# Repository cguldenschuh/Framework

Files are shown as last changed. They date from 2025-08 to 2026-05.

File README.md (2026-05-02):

# Framework Destop Tile Generator

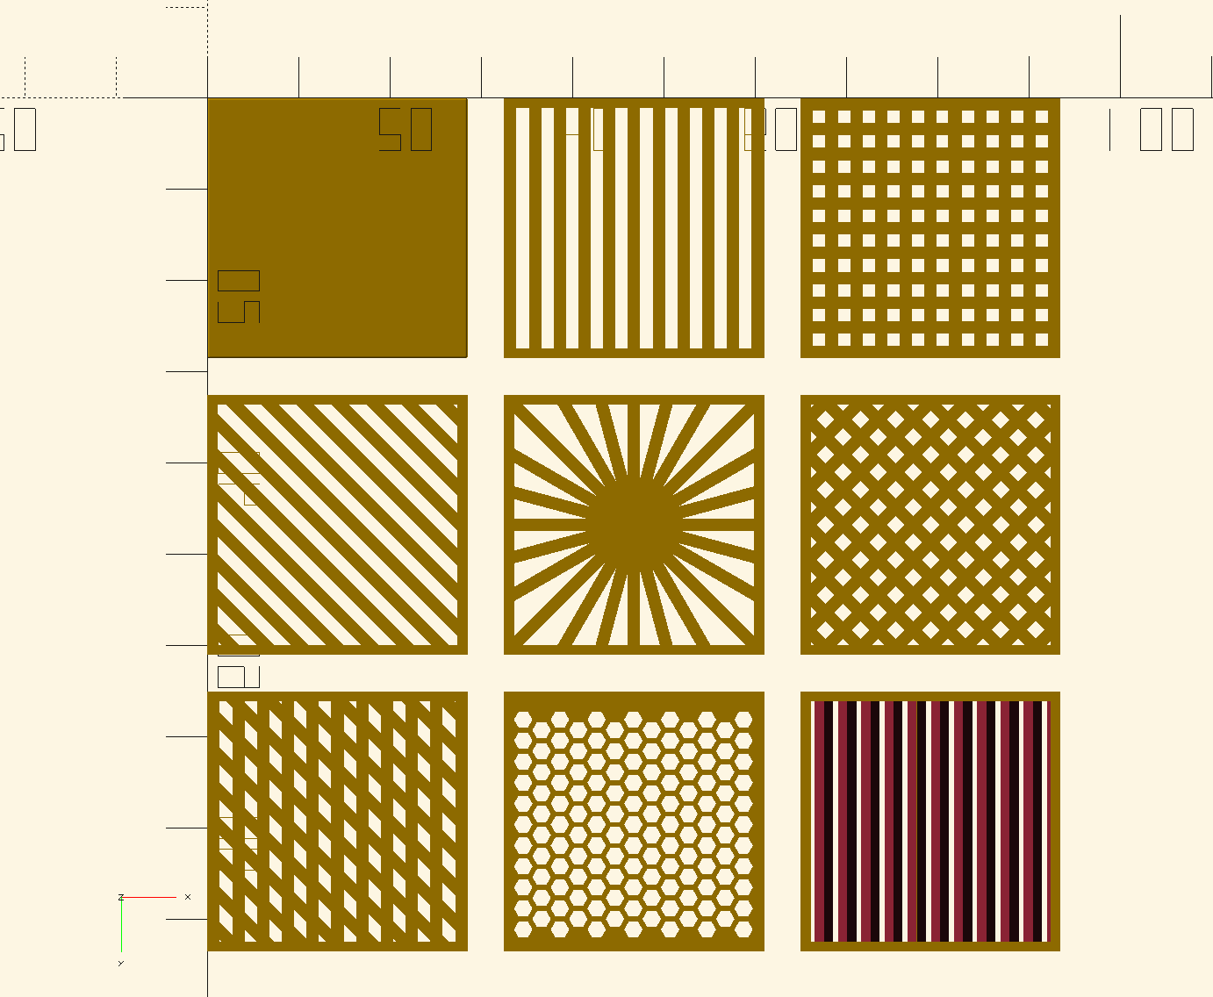
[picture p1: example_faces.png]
Example-Tiles


## License

Copyright © 2025 Charles Guldenschuh.  Licensed under CC BY 4.0.
To view a copy of this license, visit:

        https://creativecommons.org/licenses/by/4.0/

Included material:

- FRAMEWORK_DESKTOP_BLANK_TILE.stl from:
  
      https://github.com/FrameworkComputer/Framework-Desktop.git
  
  © 2025 by Framework Computer Inc is licensed under CC BY 4.0.er Inc is licensed under CC BY 4.0.

- lib_cutouts.scad (used by honeycomb) from:
  
      https://github.com/paul1522/OpenScad-Projects.git
  
  © 2019, MIT License

## What is it?

This is an OpenSCAD script to generate a handful of different tiles
for the Framework Desktop front panel.  Additionally, it can generate
multi-tile honeycomb or blank panels.

## Why is it?

* I had color preferences that weren't available from Framework
* I wanted some logo tiles that weren't available
* I'm a cheap SOB with time on my hands

## Caveats

1. These tiles fit relatively well. They are not quite as tightly bound
   to the faceplate as OEM tiles, but they won't fall out. My tiles have all
   been PLA printed on a Bambu P1S and seem to be dimensonally accurate.
2. Framework Computer has not reviewed and is not responsible for the use
   of tiles generated by this script.
3. The author assumes no responsibility for the use of this script.  To
   the best of my knowledge and testing, these tiles are akin to Legos in
   possible damage...
4. If you read the code, don't judge me... I'm retired and sometimes impatient
   with OpenSCAD, and so have generously sprinkled "magic" constants through out
   the script.  It'll get cleaned up, eventually, maybe.

## Usage

Easiest:

1. Place all of the files in one directory.
2. Open Framework_tiles_1.scad with OpenSCAD.
3. Open the **"Build Selection"** customizer section; All selections EXCEPT
   **bHoneycombMulti**, and **bMBlank** are single tiles.
4. At the top of this section is an important item:  **bMStyle** select the mount style to be used, either fully skeletonized, "blocking", solid style, or no mounts are generated (see Tips section below)
5. "Build size parameters" has a few things for special purposes:
   - **TFACE** is the thickness of the face of the tile.  My intention is that this makes the tile flush with the front of the faceplate.  See Caveats.
   - **TBORDER** is the border around the outside edge of the tile.  Mostly useful for the slat style tiles and the sunburst. It has an upper limit that is totally arbitrary.  Setting to zero may give an effect you prefer.
   - **GRIDCNT** is either the number of slats, or the number of empty spaces. Don't remember which and to lazy to look.

## Tips

1. If you are printing multiple tiles, set the print sequence to **"By object"**; you'll
   have to space them out, and will get fewer to a build plate.  You'll thank me when
   one lifts from the build plate...

2. DO NOT USE THE HONEYCOMB MULTI TILE!  The rendering is HORRIBLY slow, and
   there is a better, faster way.
   
   - Generate a multi-tile blank of the size desired.
   
   - Bring that .stl file into your slicer.
   
   - Right-click on the object and select "**Height Range Modifier"**
   
   - Set the range to start at 0mm and go to 1mm (or to the same value as you set **"Build size parameters"->TFACE**)
   
   - Select the range, and then select  the Strength tab.  Set Top shell layers and Bottom shell layers to 0. Select "Honeycomb" as the Sparse infill pattern and set the Sparse infill density to something over 20%.  Slice the plate and you're done.
   
   There are other infill patterns that are interesting (at certain densities);
   Honeycomb3D, Quarter Cubic, and Trianges for example.

3. The **"Blocking**" mount style is a solution for a "problem" that may not exist;
   Won't know until my system arrives.  With tiles that are sparsely populated, the
   faceplate supports may show through.  This was my attempt to work around it.
   Again, it may not be a problem at all.

4. All testing done with Orca Slicer 2.3.0 and a Bambu Labs P1S.  Mostly BL PLA Basic.

## Build Variables

### The tile selecton variables

| Variable | Use |
| --- | --- |
| bBlank | Blank tile |
| bHorizontal | Horizontal slats |
| bDiagonal | Diagonal slats |
| bCrosshatch | Crossed horizontal and vertical slats |
| bLattice | Crossed diagonal slats |
| bDiamond | Crossed horizontal and diagonal slats |
| bSunburst | Rayed star |
| bHgrate | Horizontal slats 45 degrees from vert |
| bHoneycomb | Honeycomb tile |
| bHoneycombMulti | Multi-tile honeycomb |
| bMBlank | Multi-tile blank |
| bFaceplate | A full faceplate for testing fit |

### Mounting selection

| Variable | Use |
| --- | --- |
| bMStyle  | Type of mount; 0=skeletonized, 1=blocking, 2=solid, 3=none |

### Multi-tile variables

| Variable  | Use |
| --- | --- |
| bHC_w | width of honeycomb multi-tile |
| bHC_h | height of honeycomb  multi-tile |
| bMB_w | width of blank  multi-tile |
| bMB_h | height of blank  multi-tile |
| bMB_style | Mount style (0=corners, 1=all, 2=select) |
| bMB_basex | vector of x locations (0-2) |
| bMB_basey | vector of y locations (0-6) |

NOTE: It is likely that the honeycomb and blank height and width parameters will be merged.

### Other sizing variables

| Variable | Use |
| --- | --- |
| TFACE | Height of the tile face |
| TBORDER  | Size of the border around the tile face [0:3] |
| GRIDCNT  | Number of slats in horizontal/diagonal tiles  |
| radi | Inner radius for honeycomb |
| rado | Outer radius for honeycomb |

## Command Line

You can run OpenSCAD from the command line to build selected .stl files.  How you do this is OS dependant, and I recommend an internet search.  I have an alias:

    alias oscad='flatpak run org.openscad.OpenSCAD'

Then:

    oscad -o blank.stl -D bBlank=true Framework_tiles_1.scad

will generate an .stl file for a blank tile.

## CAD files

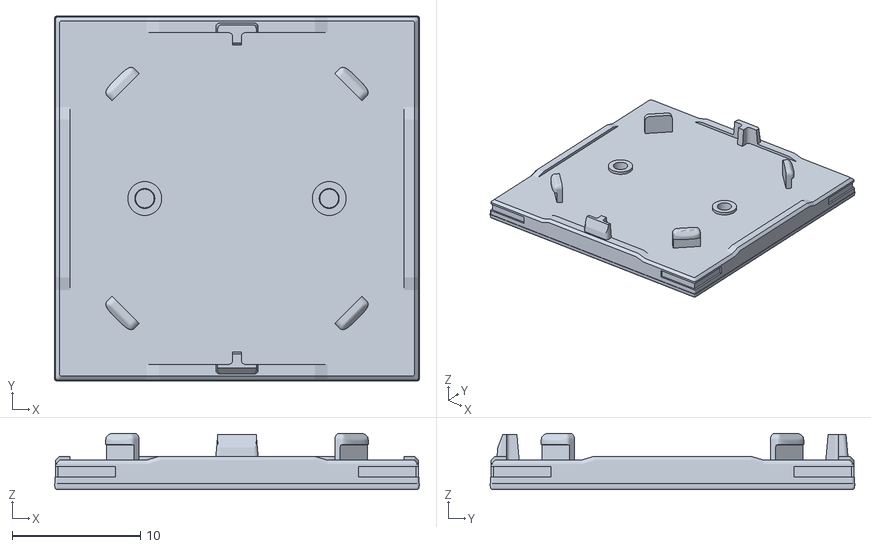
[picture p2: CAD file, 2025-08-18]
FRAMEWORK_DESKTOP_BLANK_TILE.stl
28.5 x 28.5 x 4.40

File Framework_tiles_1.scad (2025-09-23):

// Framework Desktop Tile
// Copyright (c) 2025 Charles Guldenschuh
//
//
// Framework github repository:
//
//      https://github.com/FrameworkComputer/Framework-Desktop
// 
// All dimensions from /Tiles/FRAMEWORK_DESKTOP_BLANK_TILE_V0.pdf
//
// Inspiration for the base from:
//
//  https://github.com/CavinWeber/FrameworkTiles
//
// The base tile here starts from:
//
//  https://github.com/FrameworkComputer/Framework-Desktop/Tiles/FRAMEWORK_DESKTOP_BLANK_TILE.stp
//
// Update history:
// Issue 2      20250824    cpg     clean up mount style, merge multi-tile size parameters
// Issue 4      20250825    cpg     tiles not latching
//                                  1. Adjusted tile size to match the .stl file, rather
//                                     than the .pdf. Added BASEZOFF for the mount Z offset.
//                                  2. Set the honeycomb inner radius so that the 
//                                     customizer works better.
//                                  3. Change the blank tile to use the Framework .stl
//                                     instead of building it.
//                                  4. Force the support border to be 1mm on multi-tiles.
//              20250905    cpg     added hgrate - horizontal slats twisted 45 degrees on the
//                                  long axis.
/* [Build Selection] */

// Mount style
bMStyle = 0;    // [0:Skeleton, 1:Blocking, 2:Solid, 3:None]
// Blank tile
bBlank = false;
// Horizontal slats
bHorizontal = false;
// Diagonal slats
bDiagonal = false;
// Crosshatch slats
bCrosshatch = false;
// Lattice slats
bLattice = false;
// Sunburst slats
bSunburst = false;
// Diamond lattice
bDiamond = false;
// Honeycomb - normal size tile
bHoneycomb = false;
// Horizontal grate (slats at 45 degrees)
bHgrate = false;
// Skeletonized base
bBase = false;
// Multi tile honeycomb
bHoneycombMulti = false;
// Multi tile honeycomb size
bHC_w = 3;  // [1:3]
bHC_h = 2;  // [1:7]
// Large Honeycomb mount style
bHC_mstyle = 1; // [0:None, 1:Corners, 2:All]
// Multi tile blank
bMBlank = false;
// Multi blank size
bMB_w = 3;  // [1:3]
bMB_h = 2;  // [1:7]
// Multi blank mount style
bMB_style = 1;  // [0:None, 1:Corners, 2:All, 3:Specified]
// Mount locations X
bMB_basex = [0, 0, 0, 0, 0, 0, 0];
// Mount locations Y
bMB_basey = [0, 0, 0, 0, 0, 0, 0];

// Faceplate - WIP
bFaceplate = false;
/* [Test] */
// Whatever is currently being tested
bTest = false;

/* [Hidden] */
// Tile size DO NOT CHANGE
TWIDTH = 28.5;
TDEPTH = 28.5;

// Faceplate size - WIP Height not guarenteed
FACEPLATE_WIDTH = 96.8;
FACEPLATE_HEIGHT = 214.3;   // (226.1 - 6.8 - 5?)
CUTOUT = 20;

/* [Build size parameters] */

// Face thickness
TFACE = 1;   // [.2:.2:3]
// Tile border size
TBORDER = 1.1; // [0:.1:3]
// Number of slats
GRIDCNT = 10;
GRIDGAP = ((TWIDTH - (TBORDER*2)*0) / (GRIDCNT*2+1));
//GRIDGAP = ((TWIDTH - (TBORDER*2)) / GRIDCNT);
// Honeycomb Inner radius
radi = 1.01;
// Honeycomb Outer radius
rado = 1.15;

BASEZOFF = TFACE - .1549;

//
// WIP: The faceplate for mounting the tiles
// TODO: Power switch
// TODO: Diagonal latch points
// TODO: Upper/lower alignment holes
//
module face_plate() {
    offsetx = (FACEPLATE_WIDTH - (TWIDTH * 3)) / 2;
    offsety = (FACEPLATE_HEIGHT - (TDEPTH * 7)) * 2 / 3;
    offsetc = (TWIDTH - CUTOUT) / 2;
    alignx = 2.0;
    aligny = 3.5;
    difference() {
        // The faceplate
        cube([FACEPLATE_WIDTH, FACEPLATE_HEIGHT, 4]);
        // The depression for the tiles
        translate([offsetx, offsety, 1.2]) cube([TWIDTH*3, TDEPTH*7, 4]);
        for (x=[0:2], y=[0:6]) {
            // Empty center
            translate([offsetx + TWIDTH * x + offsetc, offsety + TDEPTH * y + offsetc, 0])
                cube([CUTOUT, CUTOUT, 4]);
            // Alignment holes left and right
            translate([.2+offsetx + TWIDTH * x, TDEPTH*y+(TDEPTH)/2-aligny/2+offsety, 0]) 
                cube([alignx, aligny, 4]);
            translate([TWIDTH+offsetx-(-.95+aligny) +TWIDTH*x, TDEPTH*y + (TDEPTH)/2-aligny/2+offsety, 0]) 
                cube([alignx, aligny, 4]);
            // Alignment holes top and bottom
            translate([offsetx+TWIDTH/2-1.8+TWIDTH*x, offsety+.5+TDEPTH*y, 0])
                cube([aligny, alignx, 4]);
            translate([offsetx+TWIDTH/2-1.8+TWIDTH*x, offsety+TDEPTH-aligny+1+TDEPTH*y, 0])
                cube([aligny, alignx, 4]);
        }
    }
}

module do_test() {
    translate([-(FACEPLATE_WIDTH+4), 0, 0]) {
        translate([1.5, 1.5, 0]) linear_extrude(.1) scale([.58, .58, 0]) import("/home/cguldenschuh/Downloads/nixos-plain-logo.svg");
//        linear_extrude(TFACE) {
//            difference() {
//                square([TWIDTH, TDEPTH]);
//                rotate([0, 0, -45]) union() {
//                    for (i = [-(GRIDGAP/2):GRIDGAP*2:TWIDTH-(GRIDGAP)]) {
//                        translate([i, TBORDER*0, 0]) square([GRIDGAP, TDEPTH*sqrt(2)]);
//                        translate([-(i+GRIDGAP), TBORDER*0, 0]) square([GRIDGAP, TDEPTH*sqrt(2)]);
//                    }
//                }
//            }
//            difference() {
//                square([TWIDTH, TDEPTH]);
//                translate([TBORDER, TBORDER, 0]) square([TWIDTH-(TBORDER*2), TDEPTH-(TBORDER*2)]);
//            }
//        }
        difference() {
            honeycm(wid=3, hgt=3, bases=1);
            translate([TWIDTH, TDEPTH, 0]) cube([TWIDTH, TDEPTH, TFACE]);
        }
        translate([TWIDTH, TDEPTH, 0]) star();
        translate([TWIDTH, TDEPTH, BASEZOFF]) sbase(type=bMStyle);
    }
}

// Blank tile
module blank() {
//    cube([TWIDTH, TDEPTH, TFACE]);
    translate([-88.618, -127.535, -203.2]) 
        import("FRAMEWORK_DESKTOP_BLANK_TILE.stl", convexity=10);
}

// Horizontal/Vertical slats
module straight() {
    difference() {
        cube([TWIDTH, TDEPTH, TFACE]);
        for (i = [GRIDGAP:GRIDGAP*2:TWIDTH-(GRIDGAP)]) {
            translate([i, TBORDER, -.01]) cube([GRIDGAP, TDEPTH-(TBORDER*2), TFACE+.02]);
        }
    }
}

// Diagonal slats
module diagonal() {
    difference() {
        cube([TWIDTH, TDEPTH, TFACE]);
        rotate([0, 0, -45]) union() {
            for (i = [-(GRIDGAP/2):GRIDGAP*2:TWIDTH-(GRIDGAP)]) {
                translate([i, TBORDER*0, -.01]) cube([GRIDGAP, TDEPTH*sqrt(2), TFACE+.02]);
                translate([-(i+GRIDGAP), TBORDER*0, -.01]) cube([GRIDGAP, TDEPTH*sqrt(2), TFACE+.02]);
            }
        }
    }
    difference() {
        cube([TWIDTH, TDEPTH, TFACE]);
        translate([TBORDER, TBORDER, -.01]) cube([TWIDTH-(TBORDER*2), TDEPTH-(TBORDER*2), TFACE+.02]);
    }
}

// Mounting base
// The .stl from Frameworks github repository must be in the same directory
// as this file.
// The translate() position was calculated by an uncalibrated Mark I eyeball.
//
// The idea is to take the Framework generated blank tile, trim off the
// face, hollow out the mounting area, and add back supports for the
// mounting tabs. 
//
// These mounts are then added to the top face of the tiles (if selected) making
// the tiles ready for printing.
//
// Alternatively, the tiles and the mounting bases can be printed separately and
// connected with an appropriate glue.
//
// Type = [0: skeletonized, 1:blocking, 2:solid, 3:none]
//
module sbase(type=0) {
    if (type != 3) {
        difference() {
            translate([-88.618, -127.535, -204.]) 
//            translate([-88.6, -127.48, -203.]) 
                import("FRAMEWORK_DESKTOP_BLANK_TILE.stl", convexity=10);
            // Slice off the face of the blank
            translate([0, 0, -1]) cube([29.5, 29.5, 1]);
            if (type != 2) {
                // If not solid base, cut out interior
                translate([2, 2, 0]) cube([24.5, 24.5, 1.5]);
                translate([2, 28.5/2-1.5, 0]) cube([24.5, 3, 2]);
            }
        }
        if (type != 2) {
            // Supports for latches
            translate([9.25, 1, 0]) rotate([0, 0, 45]) cube([.7, 12, 1.5]);
            translate([18.25, 1, 0]) rotate([0, 0, -45]) cube([.7, 12, 1.5]);
            translate([27.6, 18.25, 0]) rotate([0, 0, 45]) cube([.7, 12, 1.5]);
            translate([1, 19.4, 0]) rotate([0, 0, -45]) cube([.7, 12, 1.5]);
        }
        if (type == 0) {
            // If full skeleton, add a cross brace under alignment lugs
            translate([28.5/2-.5, 1, 0]) cube([1, 26, 1.5]);
        }
        if (type == 1) {
            // If blocking, add a wider brace around the edge
            widthb = (TWIDTH - (CUTOUT * 1)) / 2 * 1 - TBORDER;
            lenb = TDEPTH - (TBORDER*2);
            translate([TBORDER, TBORDER, 0]) {
                difference() {
                    cube([lenb, lenb, TFACE+.5]);
                    translate([widthb, widthb, 0])
                        cube([lenb-(widthb*2), lenb-(widthb*2), TFACE+.5]);
                }
            }
        }
    }
}
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

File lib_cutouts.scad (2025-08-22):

module myBreadboard(w, l, ro, ri) {
	//echo(w, l, ro, ri);
	cols = floor((w - ((ro - ri) * 2)) / 2 / ro) - 1;
	rows = floor((l - ((ro - ri) * 2)) / 2 / ro) - 1;
	offx = floor((w - (cols * 2 * ro)) / 2);
	offy = floor((l - (rows * 2 * ro)) / 2);
	//echo (cols, rows);
	for (col = [0:cols]) {
		for (row = [0:rows]) {
			translate([2 * ro * col + offx, 2 * ro * row + offy, 0]) {
				circle(ri);  
			}
		}
	}
}

module myLattice(w, l, ro, ri) {
	//echo(w, l, ro, ri);
	cols = floor((w - ((ro - ri) * 2)) / ro) - 2;
	rows = floor((l - ((ro - ri) * 2)) / 2 / ro) - 1;
	offx = floor((w - (cols * ro)) / 2);
	offy = floor((l - (rows * 2 * ro)) / 2);
	//echo (cols, rows);
	for (col = [0:cols]) {
		if (col / 2 == floor(col/2)) {
			for (row = [0:rows]) {
				translate([ro * col + offx, 2 * ro * row + offy, 0]) {
					circle(ri, $fn=4);  
				}
			}
		} else {
			for (row = [0:rows-1]) {
				translate([ro * col + offx, 2 * ro * row + offy + ro, 0]) {
					circle(ri, $fn=4);  
				}
			}
		}
	}
}

module honeycomb(w, l, ro, ri, fn) {
	//echo(w, l, ro, ri);
	cols = floor((w - ((ro - ri) * 2)) / 1.75 / ro) - 1;
	rows = floor((l - ((ro - ri) * 2)) / 2 / ro) - 1;
	offx = floor((w - (cols * 1.75 * ro)) / 2);	
	offy = floor((l - (rows * 2 * ro)) / 2);
	//echo (cols, rows);
	for (col = [0:cols]) {
		if (col / 2 == floor(col/2)) {
			for (row = [0:rows]) {
				translate([1.75 * ro * col + offx, 2 * ro * row + offy, 0]) {
					circle(ri, $fn=fn);  
				}
			}
		} else {
			for (row = [0:rows-1]) {
				translate([1.75 * ro * col + offx, 2 * ro * row + offy + ro, 0]) {
					circle(ri, $fn=fn);  
				}
			}
		}
	}
}

module myHeart(w, l, ro, ri) {
	translate([w/2, l/2-ri, 0]){
		rotate([0, 0, 45]){
			translate([0, 0, 0]){
				square(2*ri);
			}
			translate([ri, 0, 0]){
				circle(ri);
			}
			translate([0, ri, 0]){
				circle(ri);
			}
		}
	}
}

module myPlane(w, l, t, ro, ri) {
	wbf = 100+(2*0.8);
	lbf = 100-(2*18.2);
	tbf = 100-(2*46.8);
	scalebf = 2*ri/wbf;
	difference() {
		linear_extrude(t) {
			difference() {
				square([w, l]);
				//myBreadboard(w, l, ro, ri);
				//myLattice(w, l, ro, ri);
				//myHoneycomb(w, l, ro, ri);
				//myHeart(w, l, ro, ri);
			}
		}
		translate([w-((w-(wbf*scalebf))/2), l-((l-(lbf*scalebf))/2), 1]) {
			rotate([0, 0, 180]) { 
				scale(scalebf){
					import("C:\\BTSync\\Paul\\Projects\\printrbot simple\\Documents\\STL Files\\butterfly.STL");
				}
			}
		}
	} 
}

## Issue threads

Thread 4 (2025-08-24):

Tiles not latching in front panel

cguldenschuh, 2025-08-24:
Tiles are not latching in the front panel printed from the .stl file published by Framework Computer.  Latches seem to be just slightly short.

cguldenschuh, 2025-08-26:
Tiles are .05 mm too small (.pdf vs .stp difference).

Closed 2025-08-26.

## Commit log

2025-08-19 Simplfy block style mounts. Default bBlank to false.
    [Framework_tiles_1.scad]
2025-08-19 Add support ridge around multi-honeycomb
    [Framework_tiles_1.scad]
2025-08-22 Remove echo statements
    [Framework_tiles_1.scad, lib_cutouts.scad]
2025-08-22 Add solid mount style
    [Framework_tiles_1.scad]
2025-08-26 Fix tile sizing/latching issue
    [Framework_tiles_1.scad]
2025-09-23 Add horizontal grate
    [Framework_tiles_1.scad]
